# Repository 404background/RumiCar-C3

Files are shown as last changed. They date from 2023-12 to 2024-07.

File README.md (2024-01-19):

# RumiCar-C3

## 車体

3DプリンターはPrusa MK4、フィラメントはPLAフィラメントを使用しています。  
[部品表](./部品表.xlsx)  
本で見つけたアッカーマン・ジャントー方式を取り入れてみました。  
サーボモーターでステアリングを操作できます。  

### 内部構造

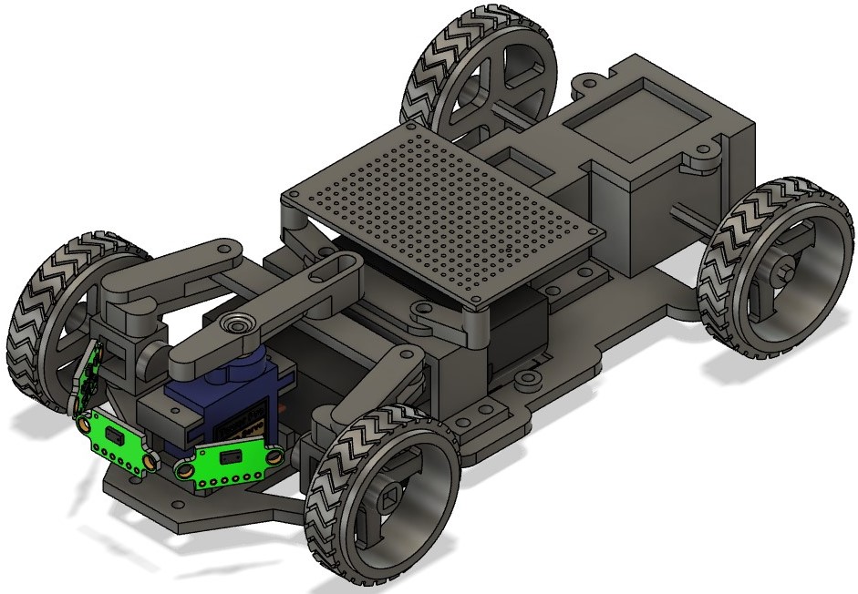
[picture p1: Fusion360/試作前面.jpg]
試作前面

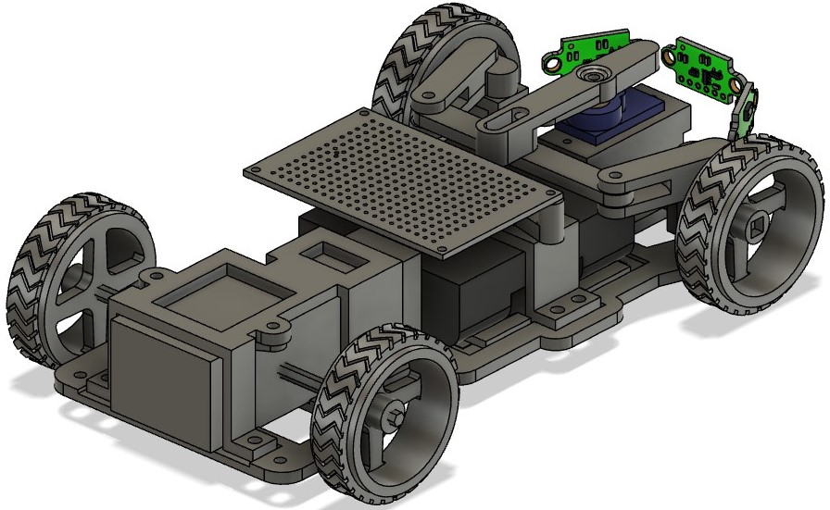
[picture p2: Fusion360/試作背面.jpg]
試作背面

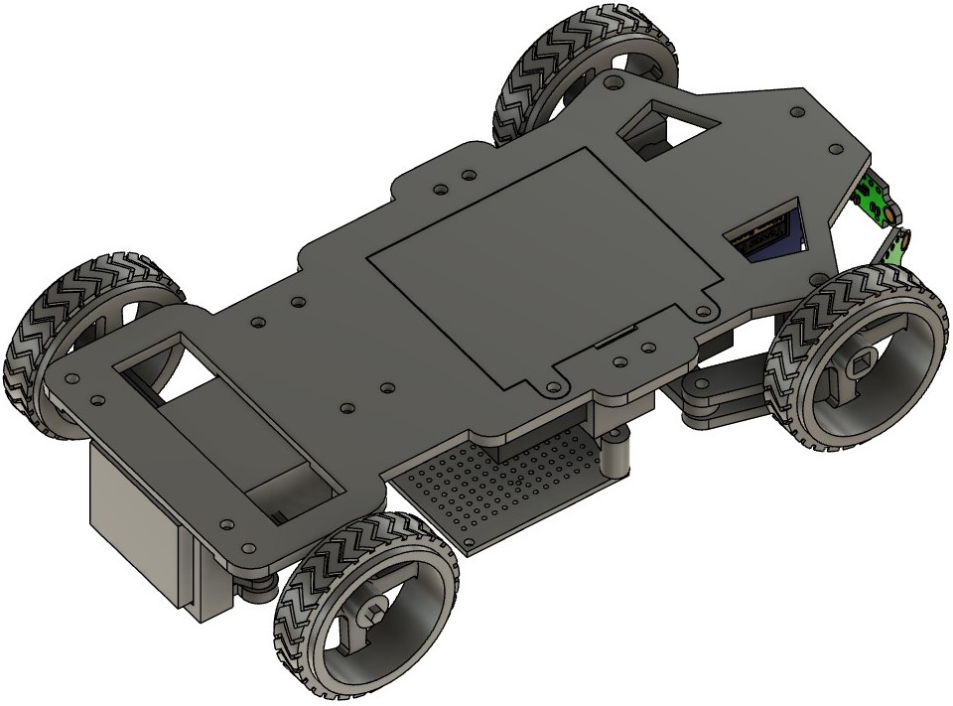
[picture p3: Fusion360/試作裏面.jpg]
試作裏面


### 外装  

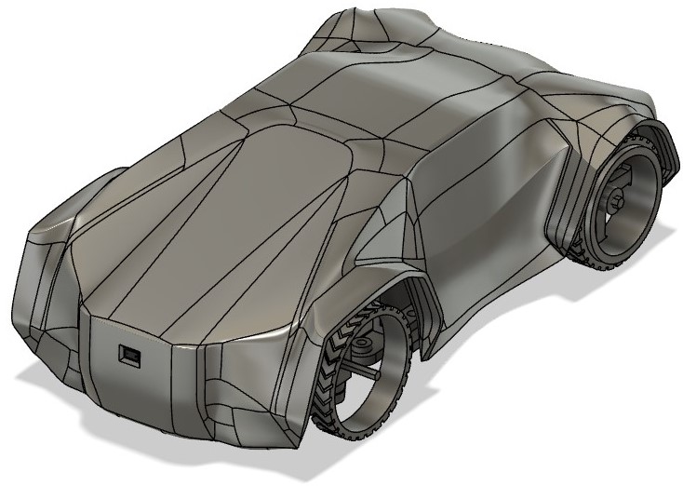
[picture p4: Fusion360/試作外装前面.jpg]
試作外装前面

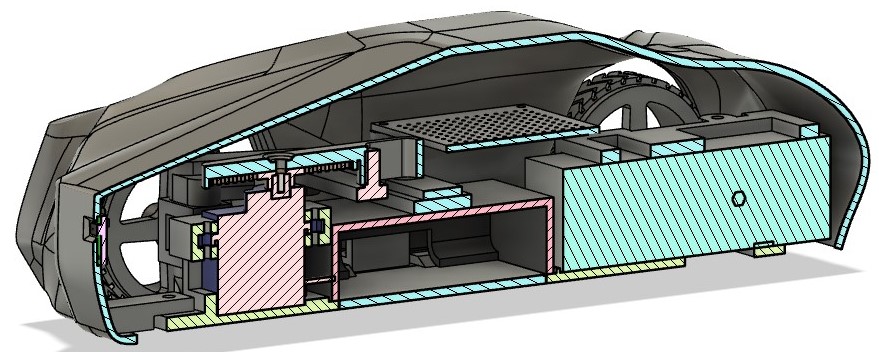
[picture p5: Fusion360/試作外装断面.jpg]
試作外装断面


### 3Dプリンターで作ったもの  

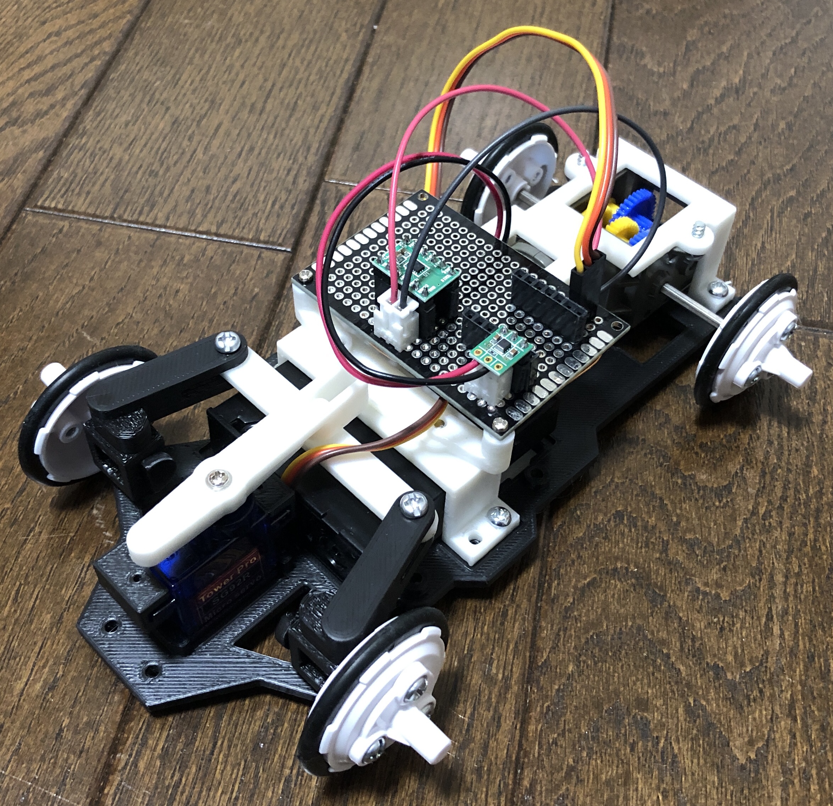
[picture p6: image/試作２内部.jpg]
試作２内部

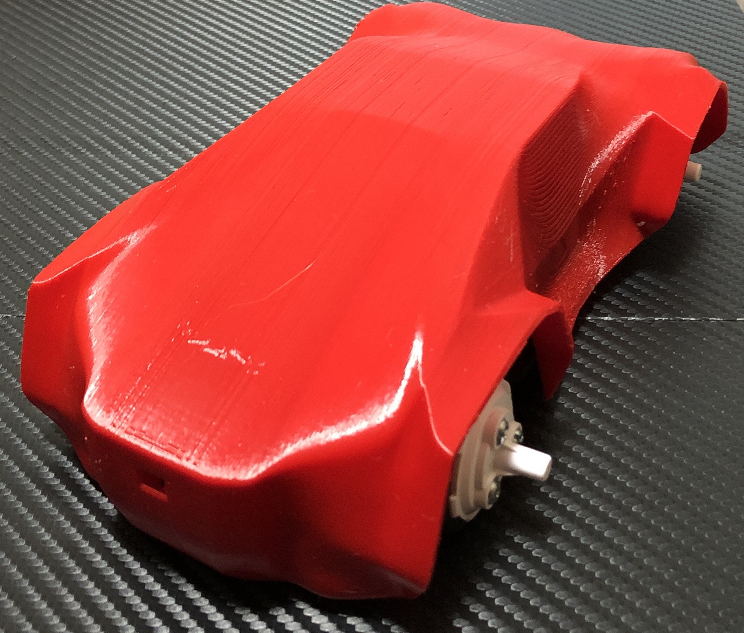
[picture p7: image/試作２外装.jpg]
試作２外装


### 動画

再生リスト：<https://www.youtube.com/playlist?list=PLf-eJAxvr1HPKLeXOhiYX_KXZIVGUdm03>  

## 回路、プログラム

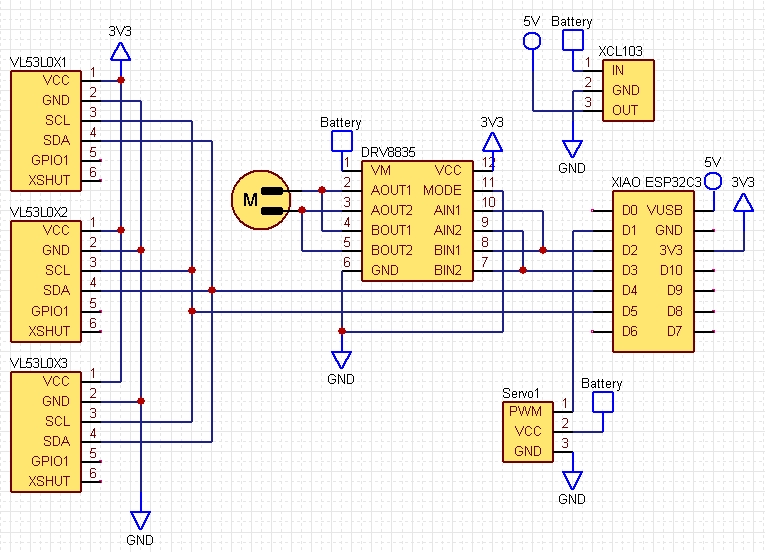
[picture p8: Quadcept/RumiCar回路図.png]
回路図試作


### DRV8835

<https://404background.com/circuit/drv8835/>  
<https://youtu.be/BTHzUvILtWA>  
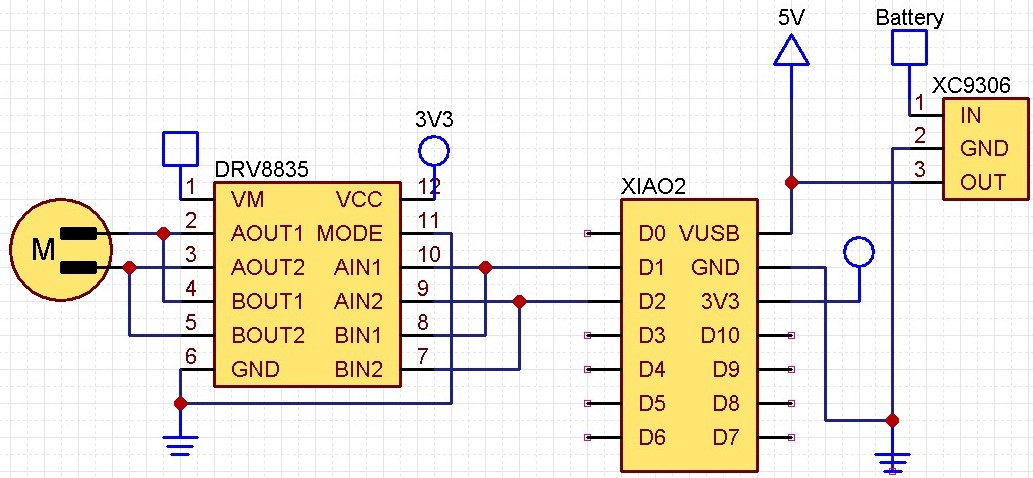
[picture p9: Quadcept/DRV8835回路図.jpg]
DRV8835回路図
  

### VL53L0X

### WiFi AP(XIAO ESP32C3)

スマートフォンからコントロールするためのプログラムです。  
<https://404background.com/program/esp32c3-4/>

## 関連記事

学生ファブリケーション2024  
<https://404background.com/made/exhibition/the-deck-2024-1-13/>

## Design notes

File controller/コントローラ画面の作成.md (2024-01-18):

# ESP32C3をスマートフォンやPCとWiFi接続して、ブラウザから操作する場合

Arduino IDEで書き込むため、コントローラ画面はC/C++のプログラム内で、文字列としてHTMLを記述することになります。  
この場合、文字列の中に含まれるダブルクォーテーションを正しく認識するため、エスケープシーケンスが必要です。  
また、複数行の文字列にするため、行末にバックスラッシュも必要です。  

このフォルダの**html_converter.py**は、html形式のテキストをC/C++で使用できるように変換するプログラムです。  

## 使い方

ターミナルでこのフォルダ内に移動して、  
`python html_converter.py HTMLのファイル名`  
を実行してください。  

tmpファイルの形式で生成されます。（.gitignoreの対象です）  

## HTMLファイルの作成

サンプルではCSS Gridで画面を構成しています。  
<https://cssgrid-generator.netlify.app/>
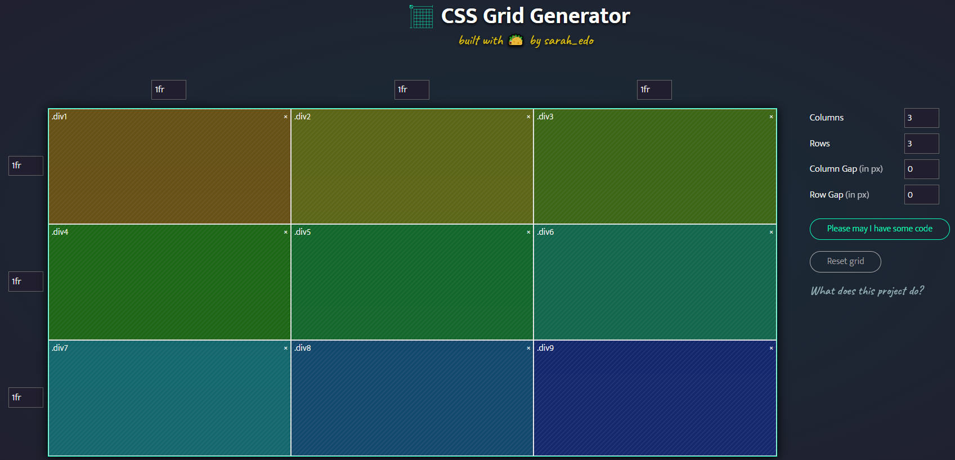
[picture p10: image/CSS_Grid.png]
CSS_Grid


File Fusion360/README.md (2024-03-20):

# Fusion360

## 出力時の注意点

- ネジはM3のタッピングネジを主に使っています。TAMIYAのギヤボックスを購入すると余るものです。
- 外装の出力が最も時間がかかり、Prusa MK4でもver1で13時間程かかりました。
- 画像のように側面を下にすると、きれいに出力できました。

Recommend:  
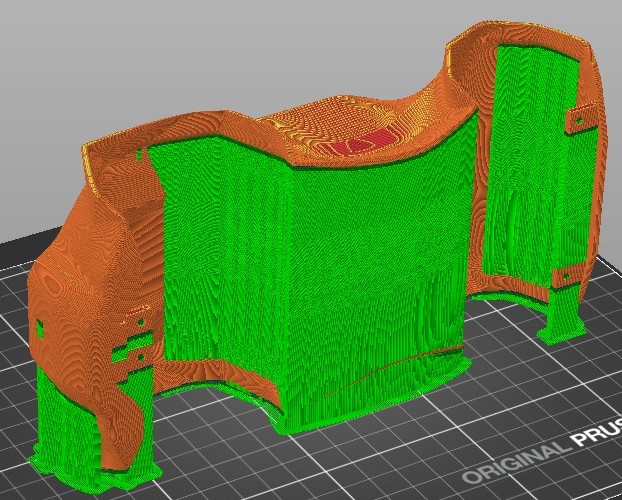
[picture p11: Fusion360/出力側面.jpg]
'出力側面'


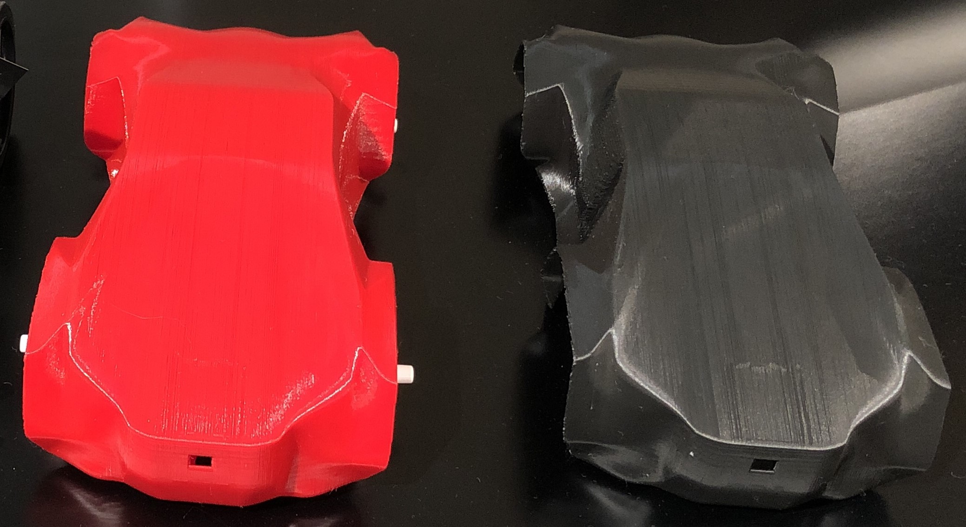
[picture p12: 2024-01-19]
image/展示３.jpg

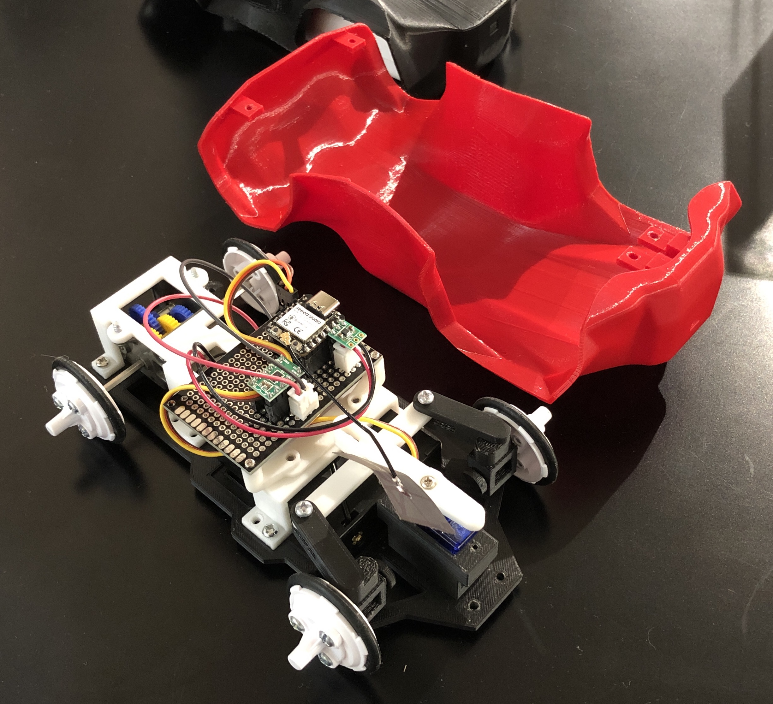
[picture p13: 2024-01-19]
image/展示２.jpg

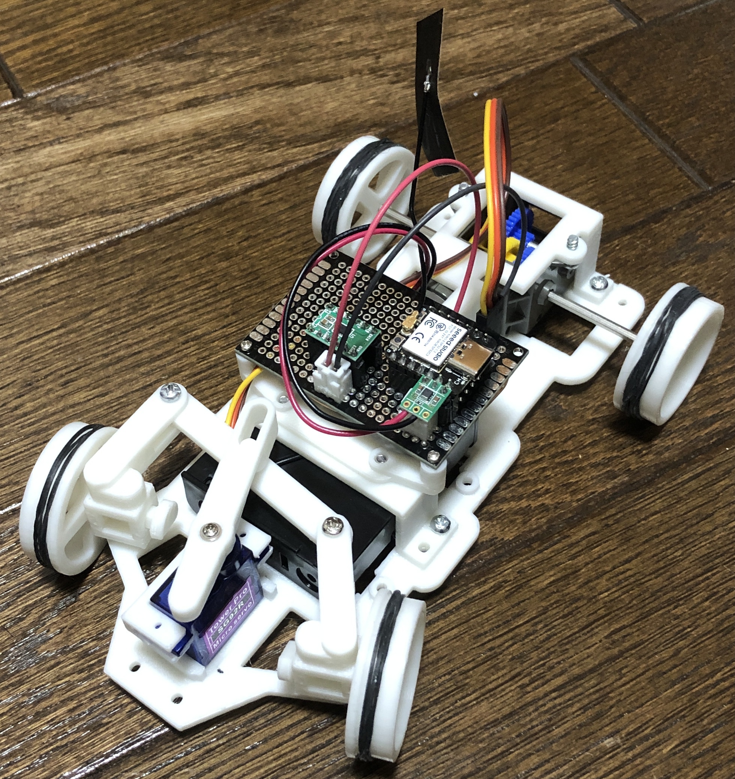
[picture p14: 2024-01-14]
image/試作１.jpg

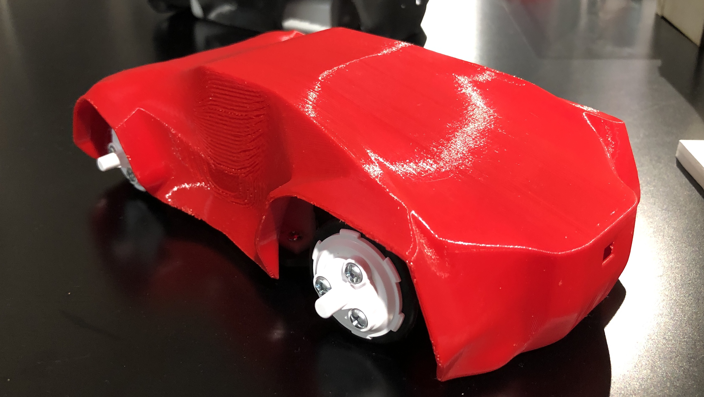
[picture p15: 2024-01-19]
image/展示１.jpg

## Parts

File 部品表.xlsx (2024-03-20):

番号 | 名称 | 販売会社 | URL | 単価 | 個数 | 合計金額 | 補足
1 | ＤＲＶ８８３５使用ステッピング＆ＤＣモータドライバモジュール | 秋月電子 | https://akizukidenshi.com/catalog/g/gK-09848/ | ¥550 | 1 | ¥550
2 | ＸＣＬ１０３使用５Ｖ出力昇圧ＤＣＤＣコンバーターキット | 秋月電子 | https://akizukidenshi.com/catalog/g/gK-15097/ | ¥300 | 1 | ¥300
3 | Ｓｅｅｅｄ Ｓｔｕｄｉｏ ＸＩＡＯ ＥＳＰ３２Ｃ３ | 秋月電子 | https://akizukidenshi.com/catalog/g/gM-17454/ | ¥940 | 1 | ¥940
4 | 電池ボックス 単3×3本 リード線 | 秋月電子 | https://akizukidenshi.com/catalog/g/g102667/ | ¥70 | 1 | ¥70
5 | マイクロサーボ ＳＧ９２Ｒ | 秋月電子 | https://akizukidenshi.com/catalog/g/gM-08914/ | ¥580 | 1 | ¥580
6 | TAMIYA シングルギヤボックス（４速タイプ） | Amazon | https://amzn.to/3TXs6yq | ¥726 | 1 | ¥726 |  | 【注意！】Amazonで買うと、最小注文個数が３でした
7 | VL53L0X(４個) | Amazon | https://amzn.to/3TS7kQW | ¥1223 | 1 | ¥1223
8 | TAMIYA トラックタイヤ | Amazon | https://amzn.to/3T9DhC4 | ¥396 | 2 | ¥792 | 36mm径 | 【注意！】Amazonで買うと、最小注文個数が３でした
9 | eSUN PLA 3Dプリンターフィラメント | Amazon | https://amzn.to/48QgeTh | ¥2699 | 1 | ¥2699
 |  |  |  |  |  | ¥7880
 | 以前使用していたもの
 | TAMIYA スリムタイヤ | Amazon | https://amzn.to/3v9O7jK | ¥371 |  |  | 36mm径を使用 | 【注意！】Amazonで買うと、最小注文個数が３でした

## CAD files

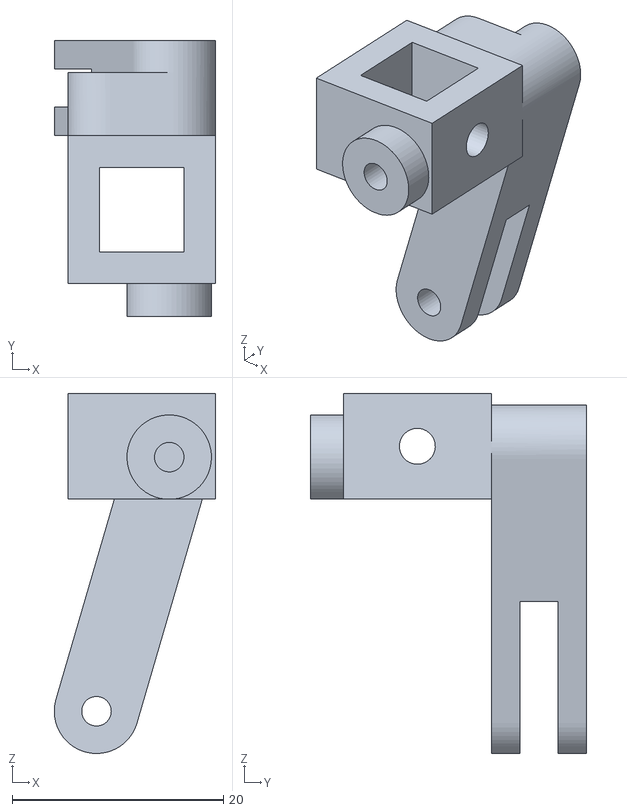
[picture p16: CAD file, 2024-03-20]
Fusion360/ver2/RumiCar_shaft_bearing_L.stl
15.3 x 26.1 x 34.1

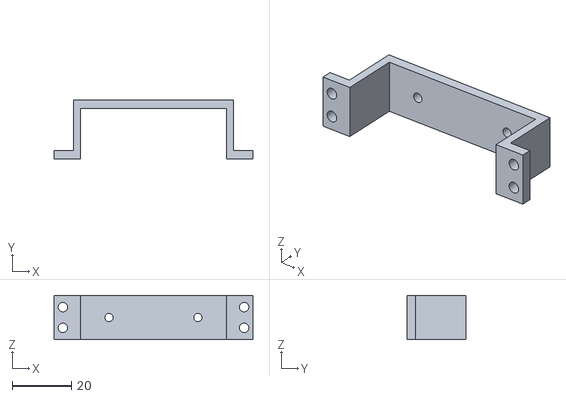
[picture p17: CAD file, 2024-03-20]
Fusion360/ver2/RumiCar_battery_fix.stl
67.1 x 20.0 x 15.0

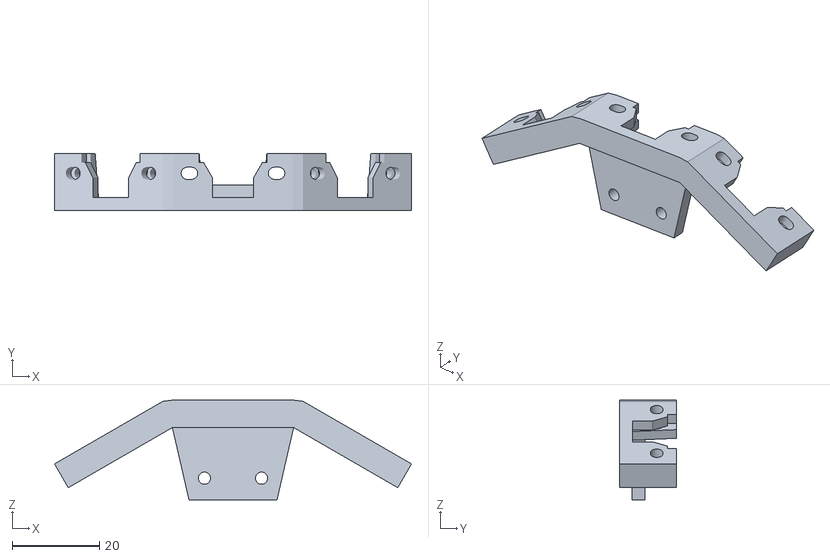
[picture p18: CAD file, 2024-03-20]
Fusion360/ver2/RumiCar-sensor.stl
81.9 x 13.0 x 22.9

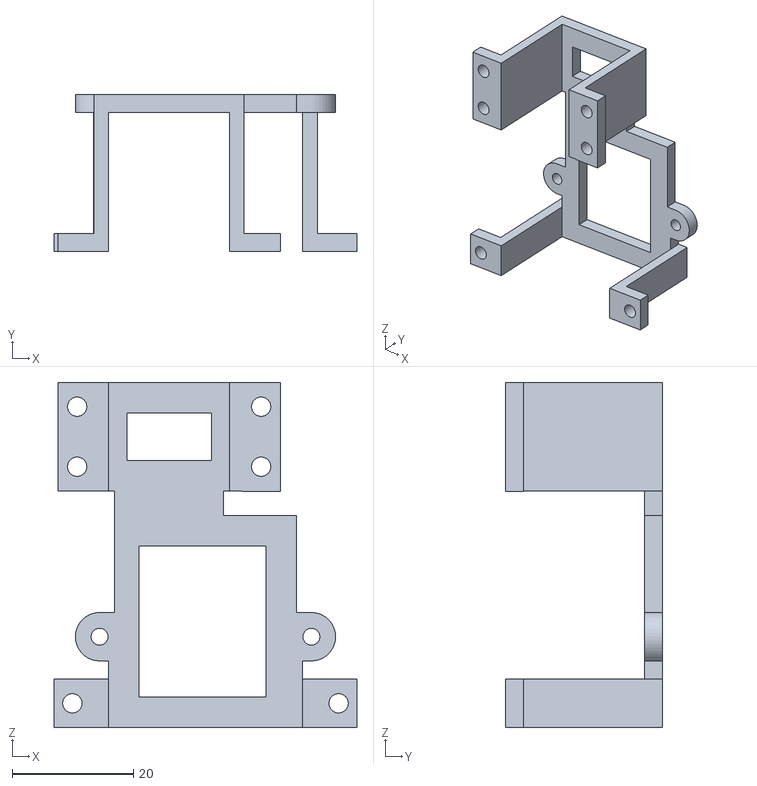
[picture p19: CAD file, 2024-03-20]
Fusion360/ver2/RumiCar_motor_fix.stl
50.0 x 26.0 x 57.0

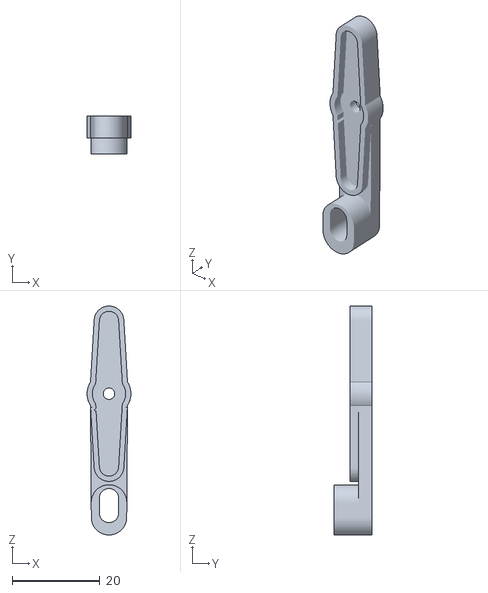
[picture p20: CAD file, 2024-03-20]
Fusion360/ver2/RumiCar_servo_horne.stl
10.0 x 8.60 x 52.2

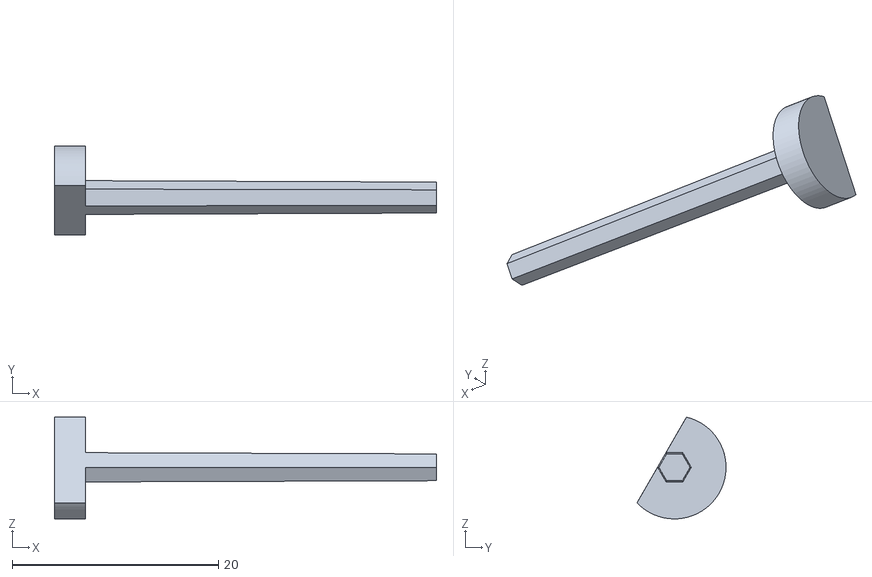
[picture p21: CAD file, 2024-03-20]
Fusion360/ver2/RumiCar_shaft.stl
37.0 x 8.63 x 9.86

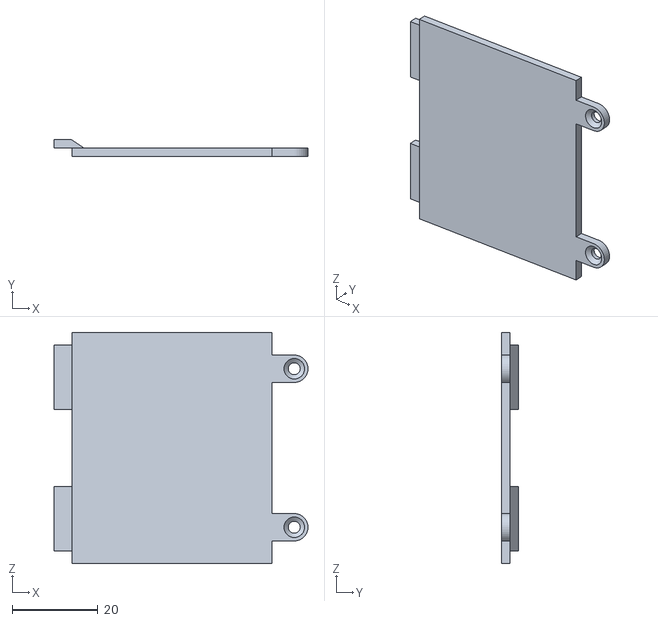
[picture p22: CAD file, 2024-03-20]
Fusion360/ver2/RumiCar_battery_cover.stl
59.3 x 4.00 x 54.0

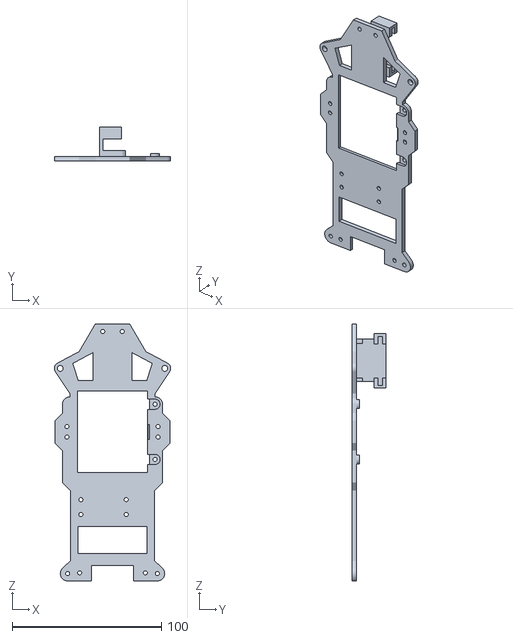
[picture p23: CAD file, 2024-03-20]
Fusion360/ver2/RumiCar_bottom.stl
78.0 x 23.0 x 172.2

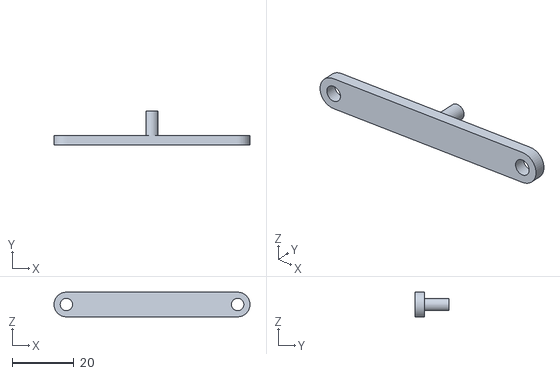
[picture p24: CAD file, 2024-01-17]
Fusion360/ver2/RumiCar_crank.stl
63.4 x 11.0 x 8.00

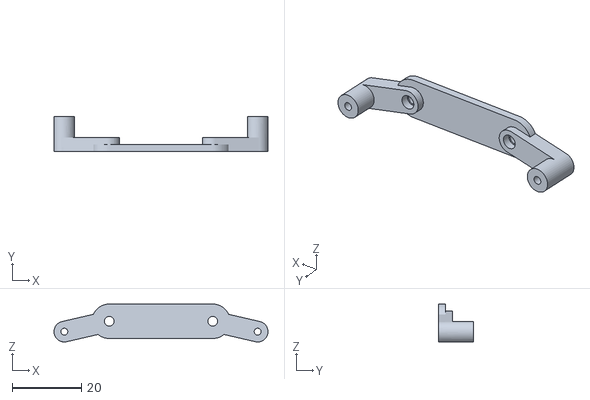
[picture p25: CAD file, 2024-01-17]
Fusion360/ver2/RumiCar_board_fix.stl
62.0 x 10.0 x 11.0

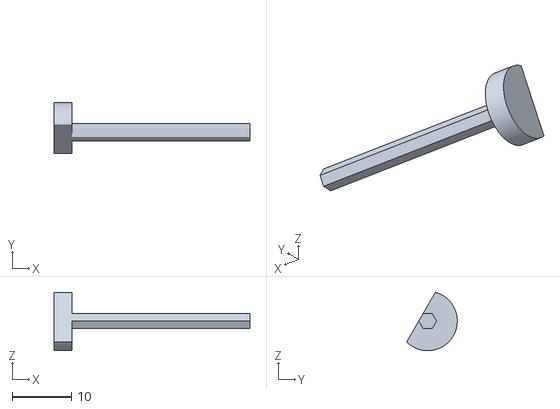
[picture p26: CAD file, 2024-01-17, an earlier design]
Fusion360/ver1/RumiCar_shaft.stl
33.0 x 8.54 x 9.83

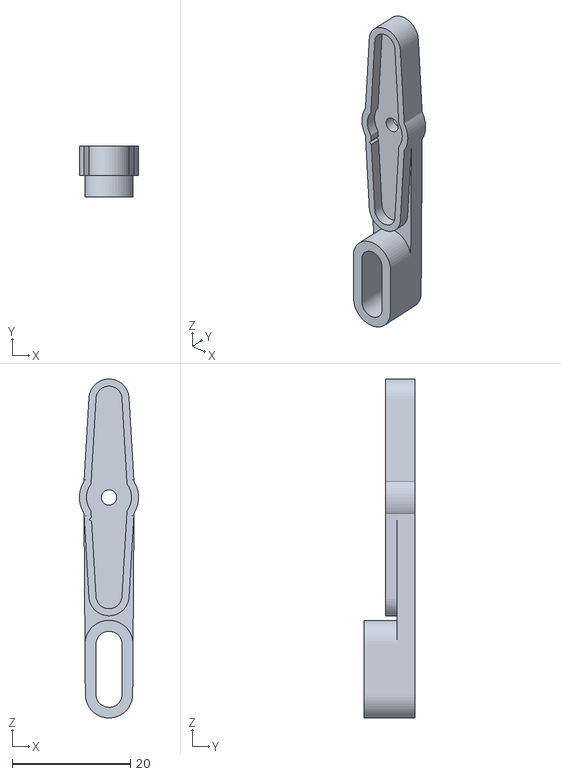
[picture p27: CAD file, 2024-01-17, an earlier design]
Fusion360/ver1/RumiCar_servo_horne.stl
10.0 x 8.60 x 57.3

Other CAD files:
Fusion360/ver2/RumiCar_shaft_bearing_R.stl
Fusion360/ver1/RumiCar_battery_cover.stl
Fusion360/ver1/RumiCar_motor_fix.stl
Fusion360/ver1/RumiCar_shaft_bearing_L.stl
Fusion360/ver1/RumiCar_bottom.stl
Fusion360/ver1/RumiCar_shaft_bearing_R.stl
Fusion360/ver1/RumiCar_battery_fix.stl

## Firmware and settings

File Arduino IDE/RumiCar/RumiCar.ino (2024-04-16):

#include <WiFi.h>
#include <WiFiClient.h>
#include <WiFiAP.h>
#include "controller.h"
const int servoPin = D1;
int DutyMax = 2500;  //180:2500  conitnuous:2300
int DutyMin = 500;   //180:500   continuout:700
int DutyCycle = DutyMin;

const int PIN_IN1 = D2;
const int PIN_IN2 = D3;
int value_IN1 = 0;
int value_IN2 = 0;

int motor1 = 0;
int motor2 = 0;
int servo1 = 90;
int speedMax = 80;   //0~255, recommend 80

const char *ssid = "RumiCar-C3";
const char *password = "12345678";
WiFiServer server(80);

void servoAngle(int pin, int angle) {
  if (angle != 0) {
    int Duty = map(angle, 0, 180, DutyMin, DutyMax);
    digitalWrite(pin, HIGH);
    delayMicroseconds(Duty);
    digitalWrite(pin, LOW);
    delayMicroseconds(20 * 1000 - Duty);
  }
}

void DRV8835(int in1, int in2) {
  pinMode(servoPin, OUTPUT);
  analogWrite(PIN_IN1, in1);
  analogWrite(PIN_IN2, in2);
}

void setup() {
  Serial.begin(115200);
  pinMode(PIN_IN1, OUTPUT);
  pinMode(PIN_IN2, OUTPUT);
  DRV8835(0, 0);
  servoAngle(servoPin, 90);

  while (!WiFi.softAP(ssid, password)) {}
  IPAddress myIP = WiFi.softAPIP();
  server.begin();
}

void loop() {
  WiFiClient client = server.available();
  servoAngle(servoPin, servo1);
  DRV8835(motor1, motor2);

  if (client) {
    String currentLine = "";
    while (client.connected()) {
      if (client.available()) {
        char c = client.read();
        if (c == '\n') {
          if (currentLine.length() == 0) {
            client.println("HTTP/1.1 200 OK");
            client.println("Content-type:text/html");
            client.println();
            client.println(controllerHTML);
            break;
          } else {
            currentLine = "";
          }
        } else if (c != '\r') {
          currentLine += c;
        }

        if (currentLine.endsWith("GET /G")) {
          motor1 = 0;
          motor2 = speedMax;
          servo1 = 90;
        }
        if (currentLine.endsWith("GET /B")) {
          motor1 = speedMax;
          motor2 = 0;
          servo1 = 90;
        }
        if (currentLine.endsWith("GET /N")) {
          motor1 = 0;
          motor2 = 0;
          servo1 = 90;
        }
        if (currentLine.endsWith("GET /R")) {
          servo1 = 60;
        }
        if (currentLine.endsWith("GET /L")) {
          servo1 = 120;
        }
        if (currentLine.endsWith("GET /LG")) {
          motor1 = 0;
          motor2 = speedMax;
          servo1 = 120;
        }
        if (currentLine.endsWith("GET /RG")) {
          motor1 = 0;
          motor2 = speedMax;
          servo1 = 60;
        }
        if (currentLine.endsWith("GET /LB")) {
          motor1 = speedMax;
          motor2 = 0;
          servo1 = 120;
        }
        if (currentLine.endsWith("GET /RB")) {
          motor1 = speedMax;
          motor2 = 0;
          servo1 = 60;
        }
      }
    }
    client.stop();
  }
}

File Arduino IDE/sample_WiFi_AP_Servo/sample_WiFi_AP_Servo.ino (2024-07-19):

#include <WiFi.h>
#include <WiFiClient.h>
#include <WiFiAP.h>

const int ServoPin1 = D1;
const int ServoPin2 = D2;
const int DutyMax = 2300;
const int DutyMin = 700;
int speed1 = 0;
int speed2 = 0;

const char *ssid = "ESP32C3";
const char *password = "123456789";
WiFiServer server(80);

int test = 12345;

String str =
  "Click <a href=\"/G\">here</a> to Gp straight.<br>"
  "Click <a href=\"/B\">here</a> to Go back.<br>"
  "Click <a href=\"/N\">here</a> to Stop.<br>"
  "Click <a href=\"/R\">here</a> to turn right.<br>"
  "Click <a href=\"/L\">here</a> to turn left.<br>";

void ServoSpeed(int pin, int speed) {
  if (speed != 0) {
    int Duty = map(speed, -10, 10, DutyMin, DutyMax);
    digitalWrite(pin, HIGH);
    delayMicroseconds(Duty);
    digitalWrite(pin, LOW);
    delayMicroseconds(20 * 1000 - Duty);
  }
}

void setup() {
  Serial.begin(115200);

  pinMode(ServoPin1, OUTPUT);
  pinMode(ServoPin2, OUTPUT);
  ServoSpeed(ServoPin1, 5);
  ServoSpeed(ServoPin2, 5);

  while (!WiFi.softAP(ssid, password)) {}
  IPAddress myIP = WiFi.softAPIP();
  Serial.print("AP IP address: ");
  Serial.println(myIP);
  server.begin();
}

void loop() {
  WiFiClient client = server.available();  // listen for incoming clients
  ServoSpeed(ServoPin1, speed1);
  ServoSpeed(ServoPin2, speed2);

  if (client) {
    String currentLine = "";
    while (client.connected()) {
      if (client.available()) {
        char c = client.read();
        if (c == '\n') {
          if (currentLine.length() == 0) {
            client.println("HTTP/1.1 200 OK");
            client.println("Content-type:text/html");
            client.println();
            client.print(str);
            client.println();
            break;
          } else {
            currentLine = "";
          }
        } else if (c != '\r') {
          currentLine += c;
        }

        if (currentLine.endsWith("GET /G")) {
          speed1 = 5;
          speed2 = -5;
        }
        if (currentLine.endsWith("GET /B")) {
          speed1 = -5;
          speed2 = 5;
        }
        if (currentLine.endsWith("GET /N")) {
          speed1 = 0;
          speed2 = 0;
        }
        if (currentLine.endsWith("GET /R")) {
          speed1 = 2;
          speed2 = 2;
        }
        if (currentLine.endsWith("GET /L")) {
          speed1 = -2;
          speed2 = -2;
        }
      }
    }
    client.stop();
  }
}

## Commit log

2023-12-14 DRV8835のサンプル追加
2024-01-14 画像、部品表追加、READMEに追記
    [部品表.xlsx]
2024-01-17 画像、stlファイルの追加
    [RumiCar_battery_cover.stl, RumiCar_battery_fix.stl, RumiCar_board_fix.stl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]
2024-01-17 READMEの修正
2024-01-18 プログラムの追加
2024-01-18 プログラムの速度調整
2024-01-19 READMEの更新
2024-01-19 画像の追加
2024-03-20 部品データの更新
    [RumiCar-sensor.stl, RumiCar_battery_cover.stl, RumiCar_battery_fix.stl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]
2024-04-16 プログラムの修正、動画の追加
